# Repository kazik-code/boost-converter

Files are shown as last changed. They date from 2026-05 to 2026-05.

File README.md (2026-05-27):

# Przetwornica Boost — README

Autorski projekt przetwornicy podwyższającej napięcie (DC-DC step-up) z regulacją napięcia wyjściowego (CV) i ograniczeniem prądowym (CC). Projekt obejmuje pełny cykl inżynierski: schemat → symulacja LTSpice → projekt PCB (KiCad) → montaż → pomiary i weryfikacja na sprzęcie.

**Projekt grupowy:** 3×Kuba, 1×Szymon

---

## Kluczowe Parametry

| Parametr | Wartość spec. |
| --- | --- |
| Częstotliwość kluczowania | ~1,6 MHz |
| Indukcyjność cewki | L1 = 40 µH |
| Pojemność wyjściowa (bulk) | C2 = 200 µF |
| Próg ograniczenia prądu (CC) | ~300 mA |
| Napięcie wyjściowe (CV) | regulowane przez RV1 |
| Napięcie wejściowe | [Vin] V |

---

## Schemat Blokowy

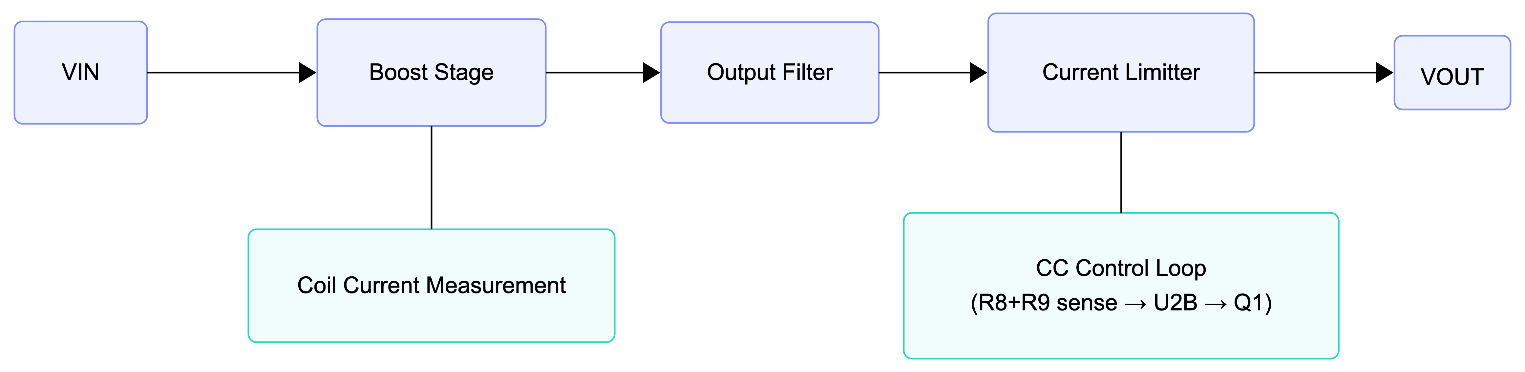
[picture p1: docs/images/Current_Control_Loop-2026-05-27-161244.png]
Current Control Loop-2026-05-27-161244.png


## Architektura Układu

### 1. Stopień Boost — LM27313XMF + L1 + D1

**LM27313XMF** to kontroler PWM przetwornicy boost o stałej częstotliwości (~1,6 MHz). Reguluje napięcie wyjściowe porównując napięcie na pinie FB z wewnętrznym napięciem referencyjnym — wyższe napięcie FB oznacza większy współczynnik wypełnienia.

Gdy wewnętrzny przełącznik (SW) zamknięty, zwiera dolny koniec cewki **L1 (40 µH)** do masy — prąd narasta, gromadząc energię w polu magnetycznym. Gdy SW otwiera się, pole opada i cewka działa jako źródło prądu napędzające wyjście do napięcia wyższego niż wejście.

**D1 (1N5822 Schottky)** — dioda swobodnego biegu. Gdy SW otwiera się, zapewnia jedyną ścieżkę przepływu prądu cewki. Bez niej zanikające pole wytworzyłoby skok napięcia niszczący U1. Schottky wybrano ze względu na niski spadek napięcia (~0,35 V vs ~0,7 V dla krzemu) i zerowy czas rekombinacji nośników odwrotnych — kluczowe przy 1,574 MHz.

**RV1 (potencjometr 100 kΩ)** ustawia napięcie na pinie FB, regulując tym samym napięcie wyjściowe. **C3 (2,2 µF)** blokuje zakłócenia HF na zasilaniu LM27313.

### 2. Filtr Wyjściowy

| Element | Wartość | Rola |
| --- | --- | --- |
| C1 | 200 pF | Ceramiczny bypass HF — tłumi szumy kluczowania |
| C2 | 200 µF | Elektrolityczny bulk — główny rezerwuar energii, stabilizuje wyjście między cyklami |
| C4 | 10 pF | Drugi bypass HF, blisko wejścia LM317 |

### 3. Pomiar Prądu Cewki — R2 + U2A

**R2 (1 Ω)** w szeregu z torem mocy (bypassowalny przez SW2). Wzmacniacz różnicowy **U2A** (LM358, R3=R4=R5=R6=9,53 kΩ, wzmocnienie = 1) mierzy spadek napięcia:

```
V_out(U2A) = I_cewki × 1 Ω
```

Wynik dostępny na **J3** do zewnętrznego pomiaru. SW2 pozwala ominąć R2 eliminując straty I²R gdy monitoring nie jest potrzebny.

### 4. Regulacja CV/CC — LM317 + U2B + Q1

**LM317 (U3)** jako liniowy regulator po stopniu boost, utrzymuje 1,25 V między OUT i ADJ. **R7** ustawia bazowe napięcie wyjściowe.

**R8 ‖ R9 = 0,5 Ω** mierzą prąd wyjściowy. **U2B** (LM358, wzmacniacz nieodwracający) wzmacnia sygnał:

```
Wzmocnienie = 1 + R11/R10 = 1 + 24k/3,3k ≈ 8,27

Przy I_out = 300 mA:
  V_sense = 0,300 × 0,5  = 0,150 V
  V_U2B   = 0,150 × 8,27 ≈ 1,24 V  ≈  V_ref(LM317) = 1,25 V
```

Gdy V_U2B ≈ 1,25 V, **Q1 (NPN)** przewodzi i ściąga pin ADJ do masy — LM317 obniża napięcie wyjściowe utrzymując I_out ≈ 300 mA (tryb CC). Poniżej progu Q1 zatkany, LM317 reguluje normalnie (tryb CV). Elegancja projektu: próg CC jest wyznaczony przez napięcie referencyjne samego LM317 — bez osobnego komparatora.

---

## Schemat i PCB

### Schemat (KiCad)

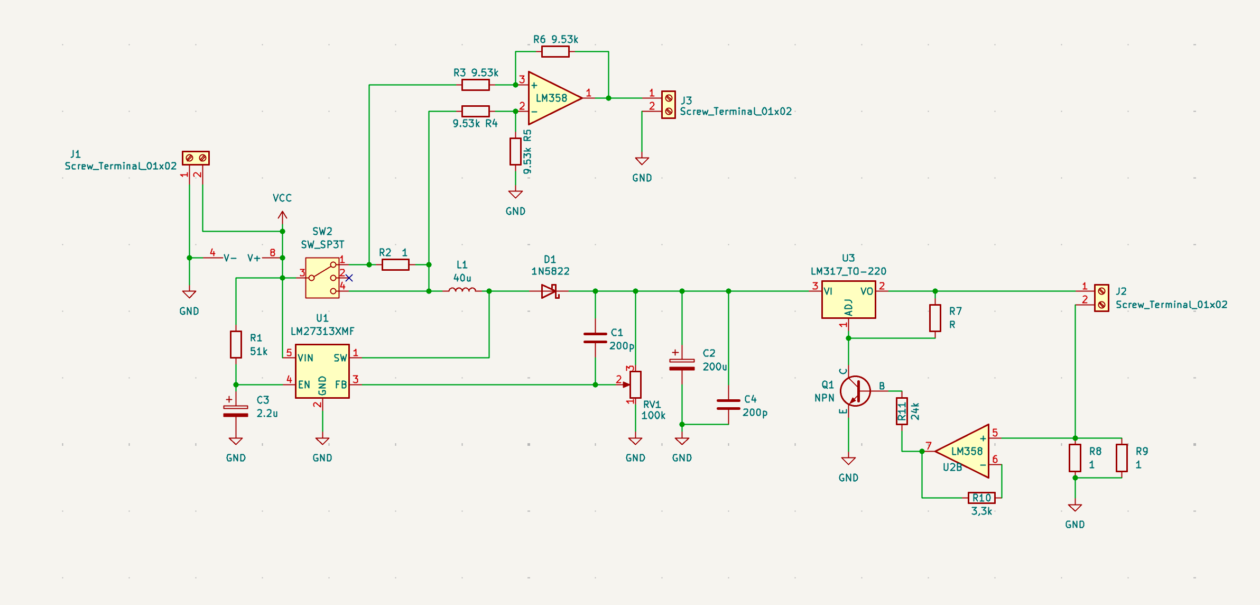
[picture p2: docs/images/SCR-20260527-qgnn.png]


### Render 3D PCB

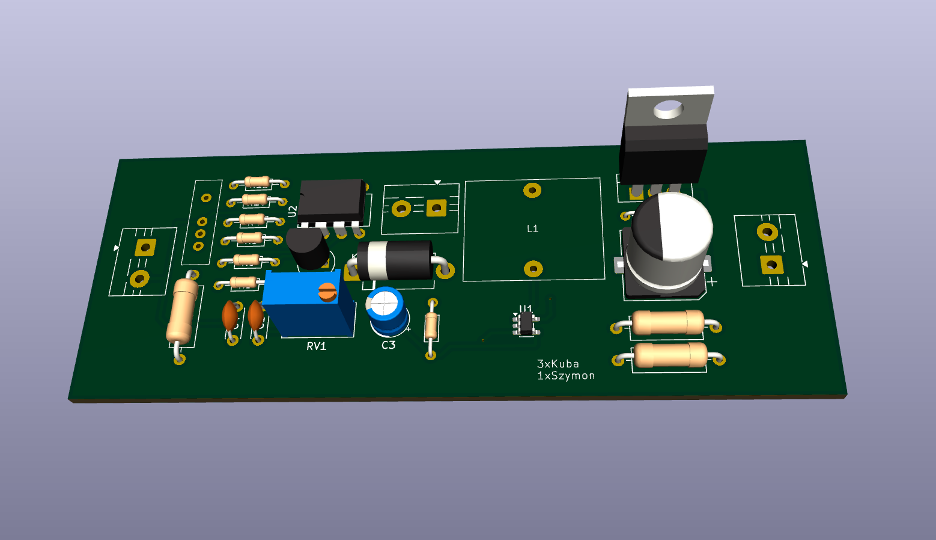
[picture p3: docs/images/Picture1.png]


### Zmontowana płytka

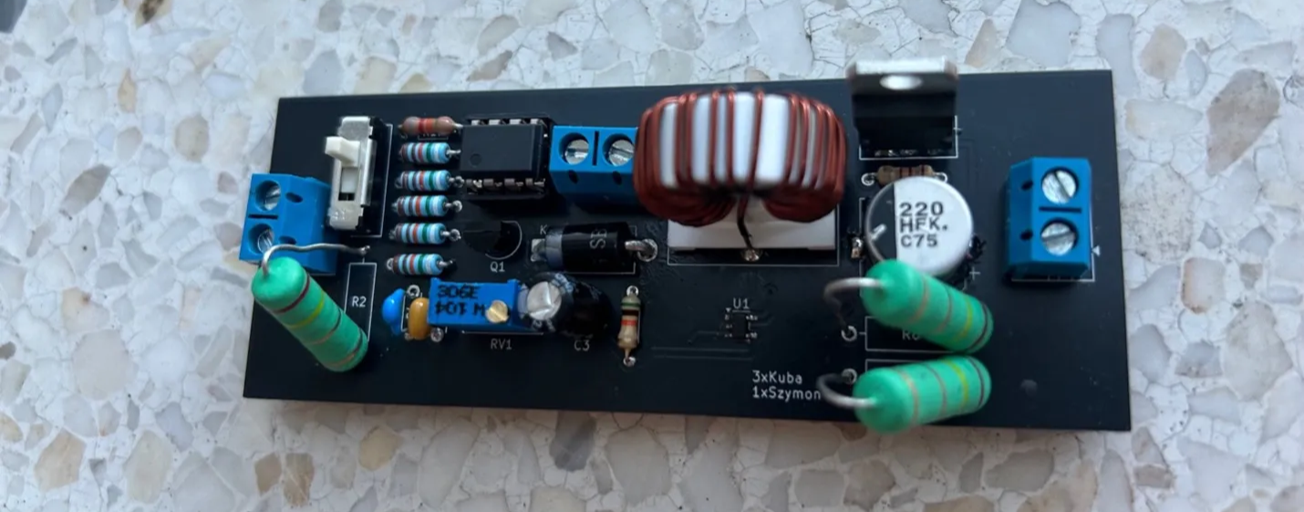
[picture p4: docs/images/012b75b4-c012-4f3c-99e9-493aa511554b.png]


Płytka dwuwarstwowa z wyraźną separacją torów mocy i sygnałowych. Toroidalny rdzeń cewki L1, LM317 z radiatorem, kondensatory elektrolityczne i wyjściowe listwy śrubowe.

---

## Symulacja (LTSpice)

### Prąd cewki I(L1) i sygnał kluczujący

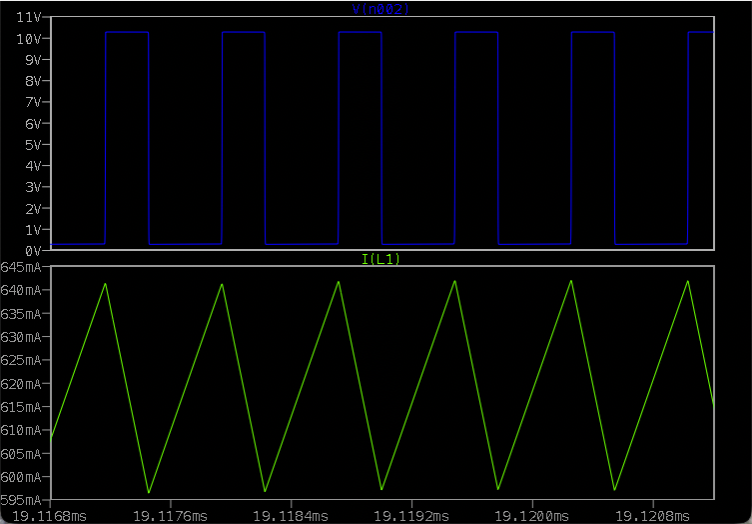
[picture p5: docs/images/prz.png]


---

## Pomiary na Sprzęcie

**Sprzęt:** Rigol MSO5204 (200 MHz, 8 GSa/s)

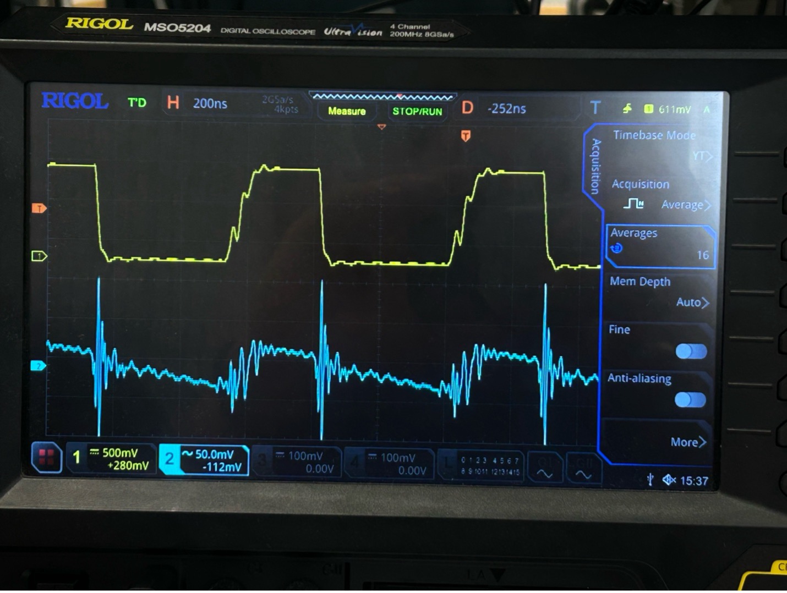
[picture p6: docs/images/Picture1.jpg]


### Prąd cewki i sygnał kluczujący — pomiar rzeczywisty

**Obserwacja — zniekształcenia pomiaru prądu:**

Pomiar prądu cewki w rzeczywistości wykazuje znaczny szum w porównaniu do symulacji. Przyczyny:

- Sygnał przełączający LM27313 (1,574 MHz) ma bardzo krótkie czasy narastania/opadania generujące harmoniczne rzędu 10–100 MHz
- Pasożytnicza indukcyjność ścieżek PCB i elementów w pętli kluczowania tworzy impulsy napięciowe przy każdym przełączeniu
- Te szybkie transjenty są indukowane (sprzężenie pojemnościowe i indukcyjne) do ścieżki pomiaru prądu
- Efektywna szerokość pasma toru pomiaru (R2 → U2A → J3 → sonda) jest ograniczona, co wypacza kształt sygnału

Wyniku nie należy interpretować jako błędu układu — przetwornica działa poprawnie, co potwierdza pomiar częstotliwości.

### Pomiar częstotliwości kluczowania

> 📎 Wstaw zdjęcie z oscyloskopu — pomiar kursorem (Δx = 635 ns)
> 

| Parametr | Wartość |
| --- | --- |
| Zmierzona częstotliwość | **1,574 MHz** |
| Metoda pomiaru | kursor ΔX: Δx = 635 ns → f = 1/635 ns |
| Specyfikacja LM27313 | ~1,6 MHz (typ.) |
| Odchyłka od specyfikacji | **1,6%** — w granicach tolerancji |

---

## Uwagi do Layoutu PCB

- **Tor mocy (VIN → L1 → D1 → C2 → LM317 → J2):** krótkie i szerokie ścieżki — każda dodatkowa impedancja w tej pętli pogarsza sprawność i zwiększa EMI
- **Kondensatory blokujące (C3, C1, C4):** umieszczone jak najbliżej pinów zasilania układów scalonych
- **Rezystory pomiarowe (R2, R8, R9):** połączenia Kelvin (oddzielne ścieżki prądu i pomiaru) eliminują błąd od rezystancji ścieżki
- **Masa:** ciągłe wypełnienie miedzią z separacją głośnego prądu kluczowania od cichego toru analogowego (LM358, dzielnik FB)
- **Punkty testowe:** VIN, węzeł SW (U1 pin 1), wyjście L1/anoda D1, VOUT, J3 (monitor cewki)

---

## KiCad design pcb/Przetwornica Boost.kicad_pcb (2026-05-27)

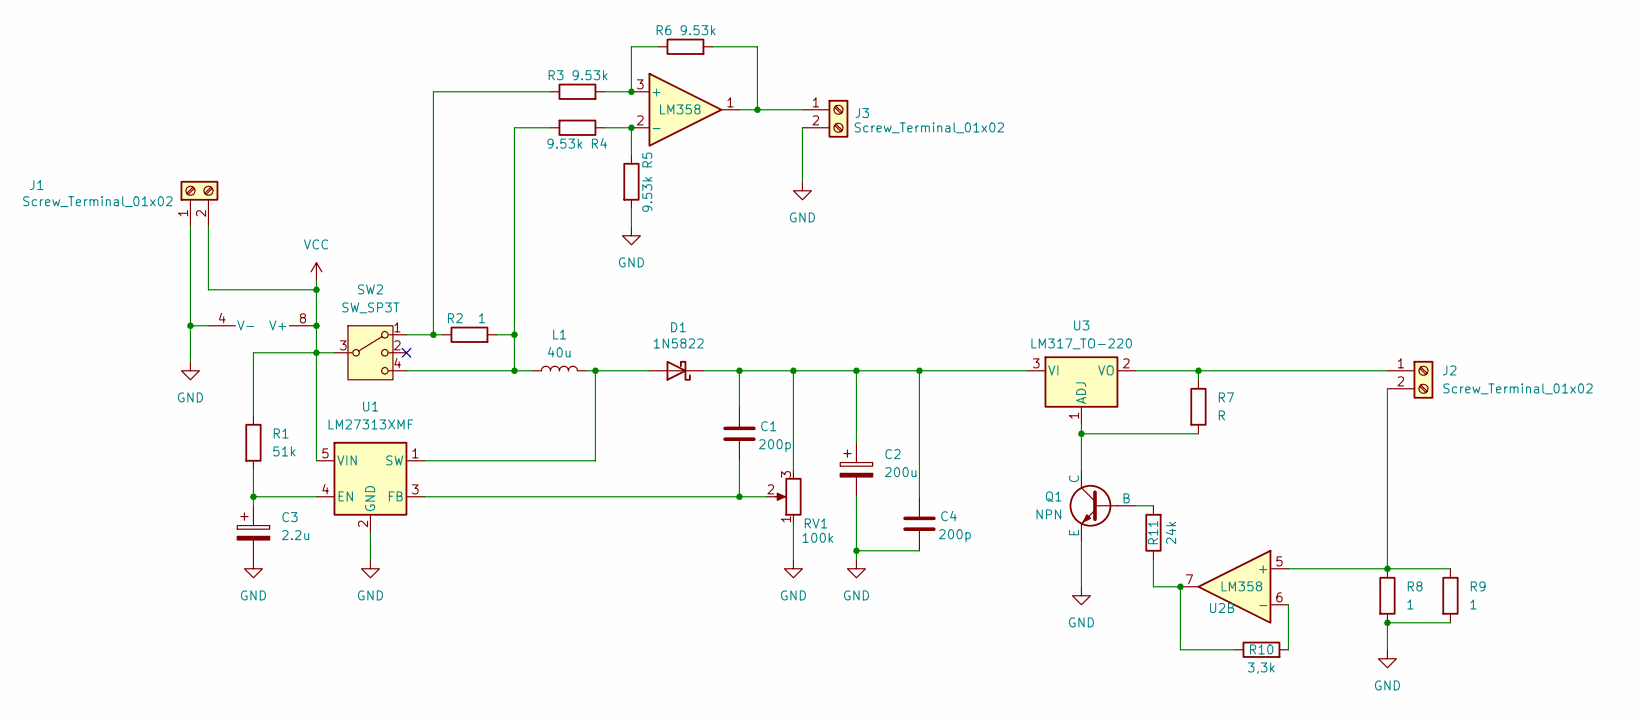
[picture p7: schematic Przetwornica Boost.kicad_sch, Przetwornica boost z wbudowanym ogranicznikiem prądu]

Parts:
C1, C4: 200p; C_Disc_D4.3mm_W1.9mm_P5.00mm
C2: 200u; CP_Elec_10x10.5
C3: 2.2u; CP_Radial_D5.0mm_P2.50mm
D1: 1N5822; D_DO-201_P12.70mm_Horizontal
J1, J2, J3: Screw_Terminal_01x02; TerminalBlock_MaiXu_MX126-5.0-02P_1x02_P5.00mm
L1: 40u; Inductor L1
Q1: NPN; TO-92_Inline
R1: 51k; R_Axial_DIN0204_L3.6mm_D1.6mm_P7.62mm_Horizontal
R2, R8, R9: 1; R_Axial_DIN0309_L9.0mm_D3.2mm_P12.70mm_Horizontal
R3, R4, R5, R6: 9.53k; R_Axial_DIN0204_L3.6mm_D1.6mm_P7.62mm_Horizontal
R7: R; R_Axial_DIN0204_L3.6mm_D1.6mm_P7.62mm_Horizontal
R10: 3,3k; R_Axial_DIN0204_L3.6mm_D1.6mm_P7.62mm_Horizontal
R11: 24k; R_Axial_DIN0204_L3.6mm_D1.6mm_P7.62mm_Horizontal
RV1: 100k; Potentiometer_Bourns_3296W_Vertical
SW2: SW_SP3T; Switch
U1: LM27313XMF; SOT-23-5
U2: LM358; DIP-8_W7.62mm
U3: LM317_TO-220; TO-220-3_Vertical

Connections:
GND: C2.2, C3.2, C4.2, J1.1, J3.2, Q1.3 (E), R5.2, R8.2, R9.2, RV1.1, U1.2 (GND), U2.4 (V-)
unnamed: D1.2 (A), L1.2, U1.1 (SW)
unnamed: C1.1, C2.1, C4.1, D1.1 (K), RV1.3, U3.3 (VI)
unnamed: J2.1, R7.1, U3.2 (VO)
unnamed: J2.2, R8.1, R9.1, U2.5 (+)
unnamed: J3.1, R6.2, U2.1
unnamed: L1.1, R2.2, R4.2, SW2.4
unnamed: Q1.2 (B), R11.2
unnamed: Q1.1 (C), R7.2, U3.1 (ADJ)
unnamed: R2.1, R3.1, SW2.1
unnamed: R10.1, R11.1, U2.7
unnamed: C3.1, R1.2, U1.4 (EN)
unnamed: C1.2, RV1.2, U1.3 (FB)
unnamed: R3.2, R6.1, U2.3 (+)
unnamed: R4.1, R5.1, U2.2 (-)
unnamed: R10.2, U2.6 (-)
VCC: J1.2, R1.1, SW2.3, U1.5 (VIN), U2.8 (V+)

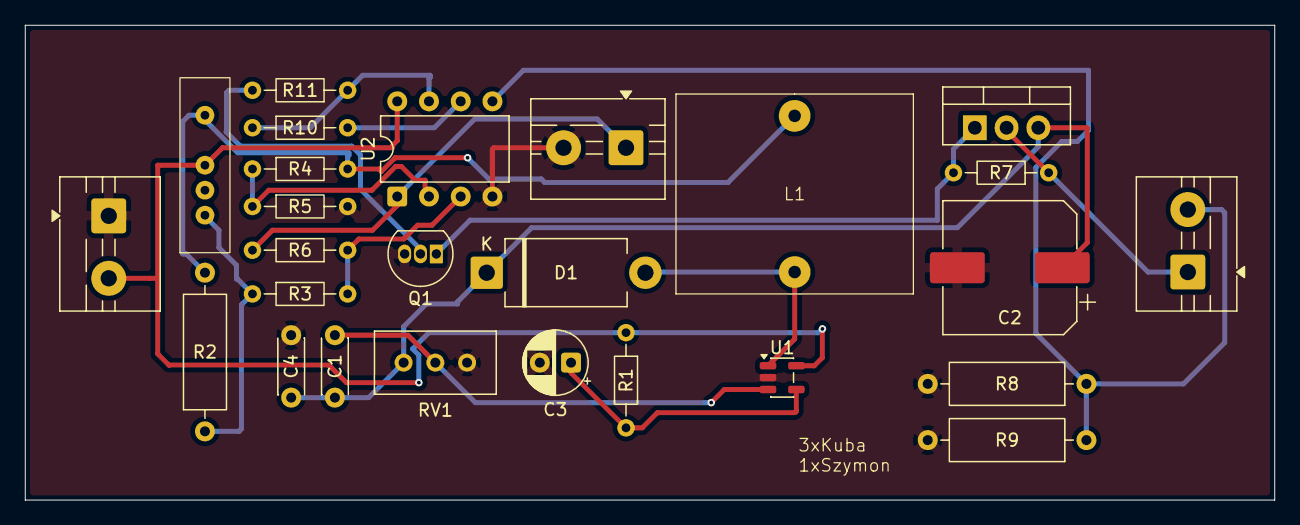
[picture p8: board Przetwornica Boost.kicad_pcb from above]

Board: 4 copper layers, 100.0 x 38.0 mm, 26 parts (0 on the bottom side), 17 nets.
